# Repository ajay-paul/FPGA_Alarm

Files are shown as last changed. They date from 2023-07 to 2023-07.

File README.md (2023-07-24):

# FPGA_Alarm
 
Developed and implemented an alarm system using VHDL on a Nexys A7 FPGA board. Integrated a 4x4 Matrix keypad for user input. Employed Kicad to design a custom PCB for the project. The alarm system incorporated users to input a correct 4-digit password via the keypad, which was then displayed on a 7-segment display.
3D_View
Routing
FPGA_Correct
FPGA_False

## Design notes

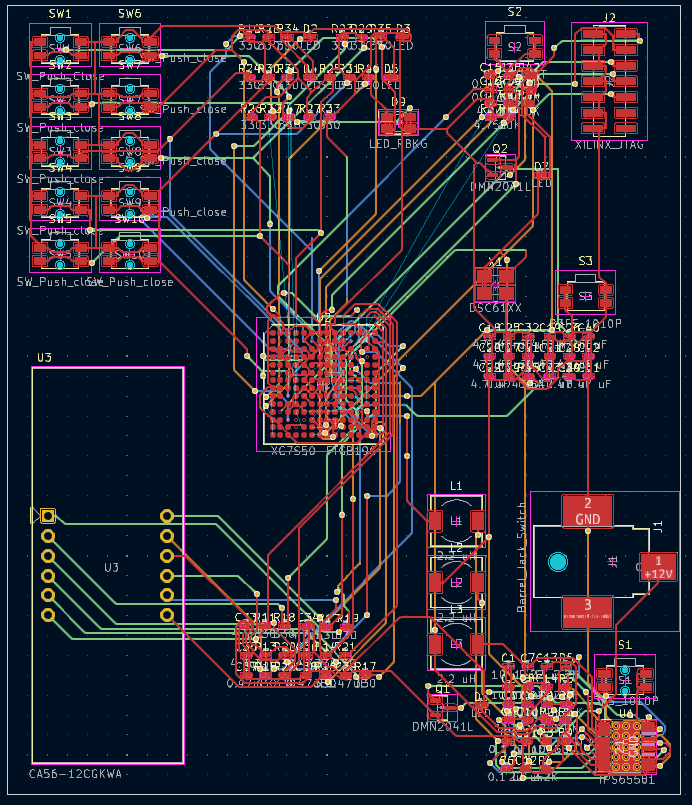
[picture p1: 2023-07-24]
PCB_Desgin/Routing.PNG

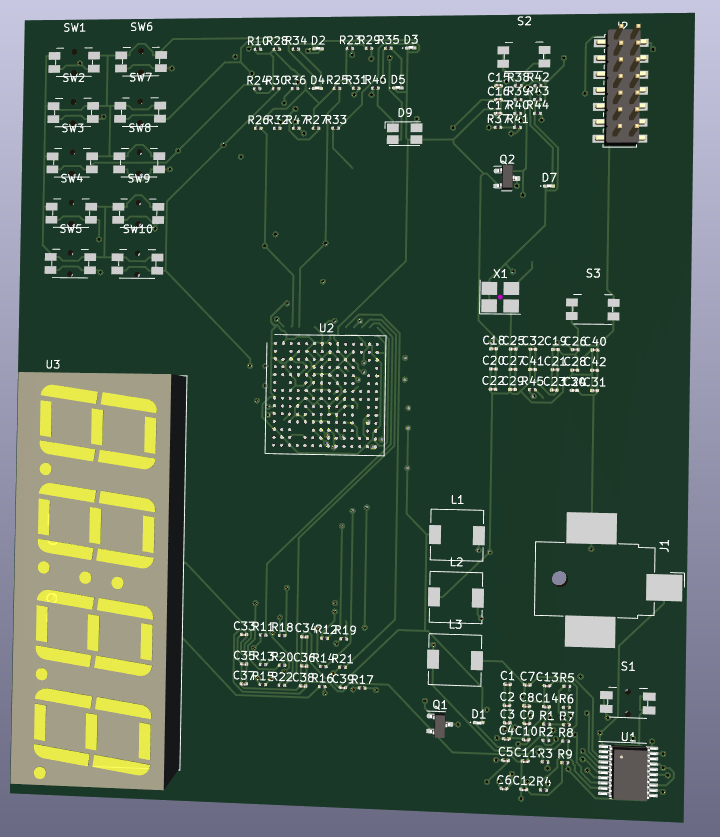
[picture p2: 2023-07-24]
PCB_Desgin/3D_View.PNG

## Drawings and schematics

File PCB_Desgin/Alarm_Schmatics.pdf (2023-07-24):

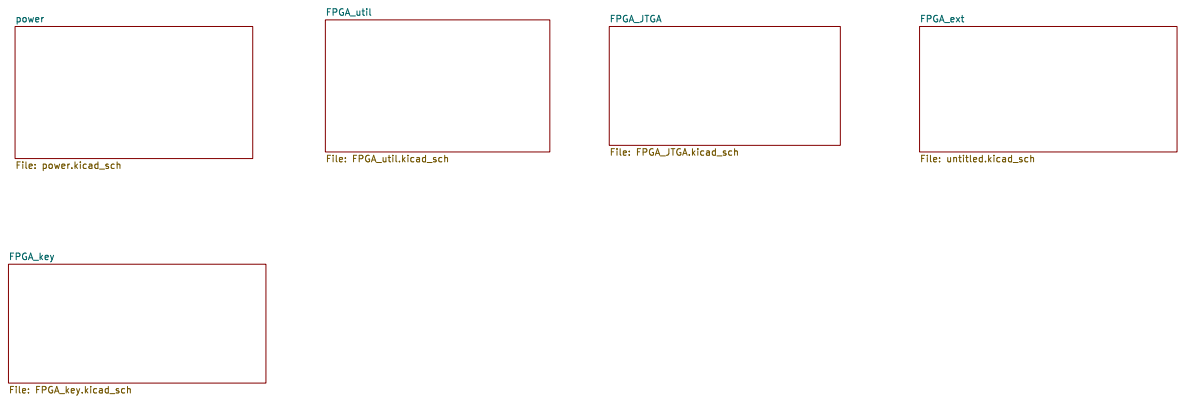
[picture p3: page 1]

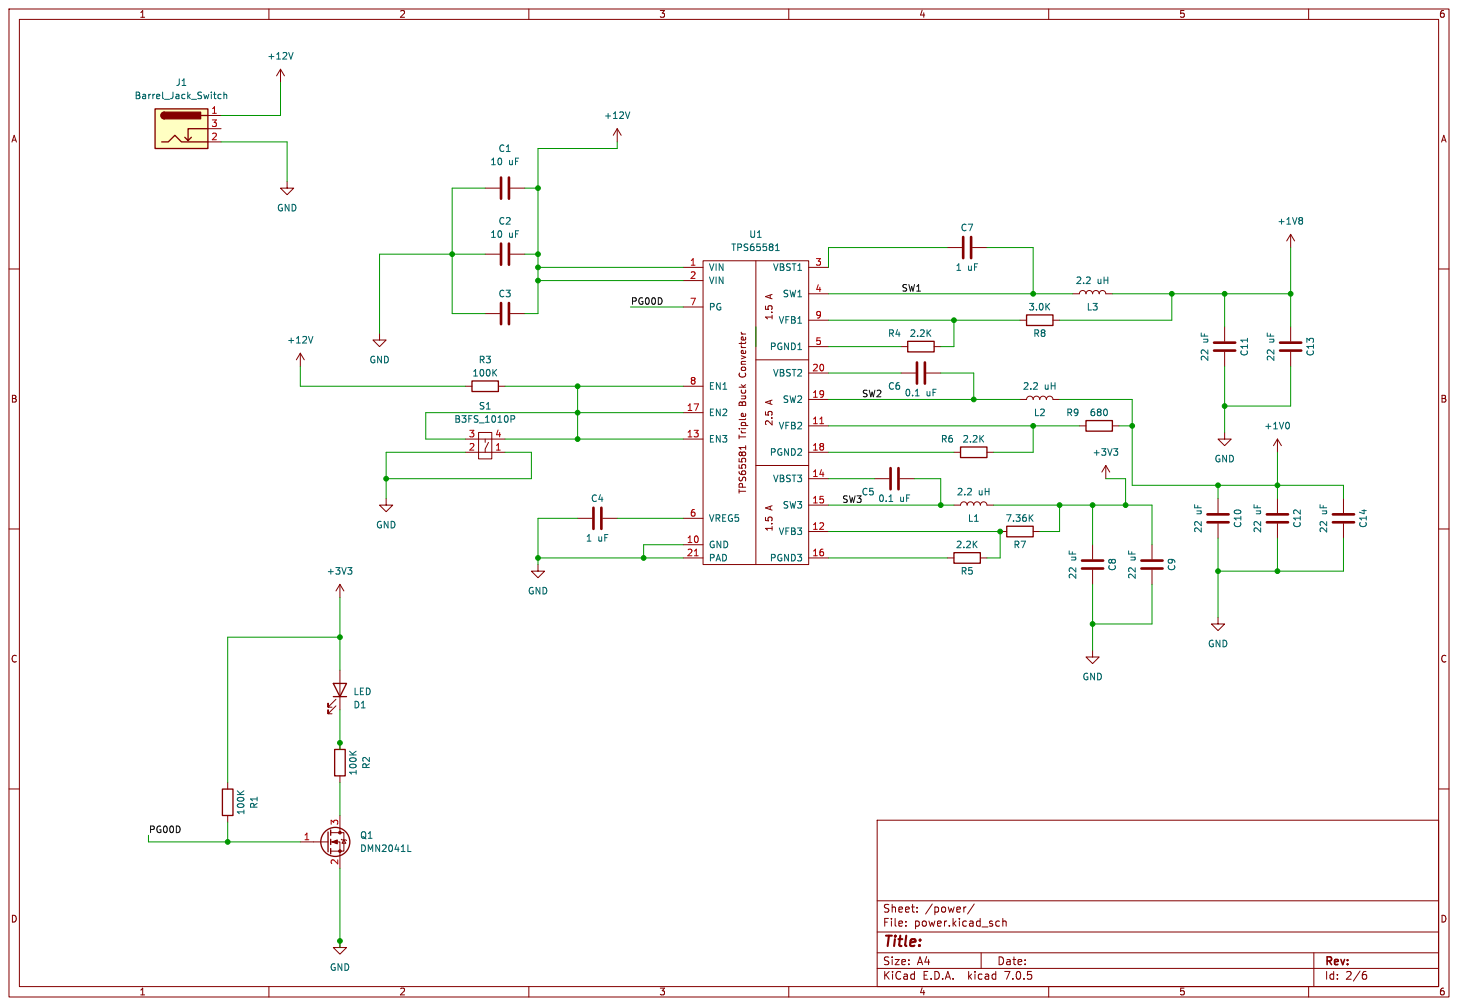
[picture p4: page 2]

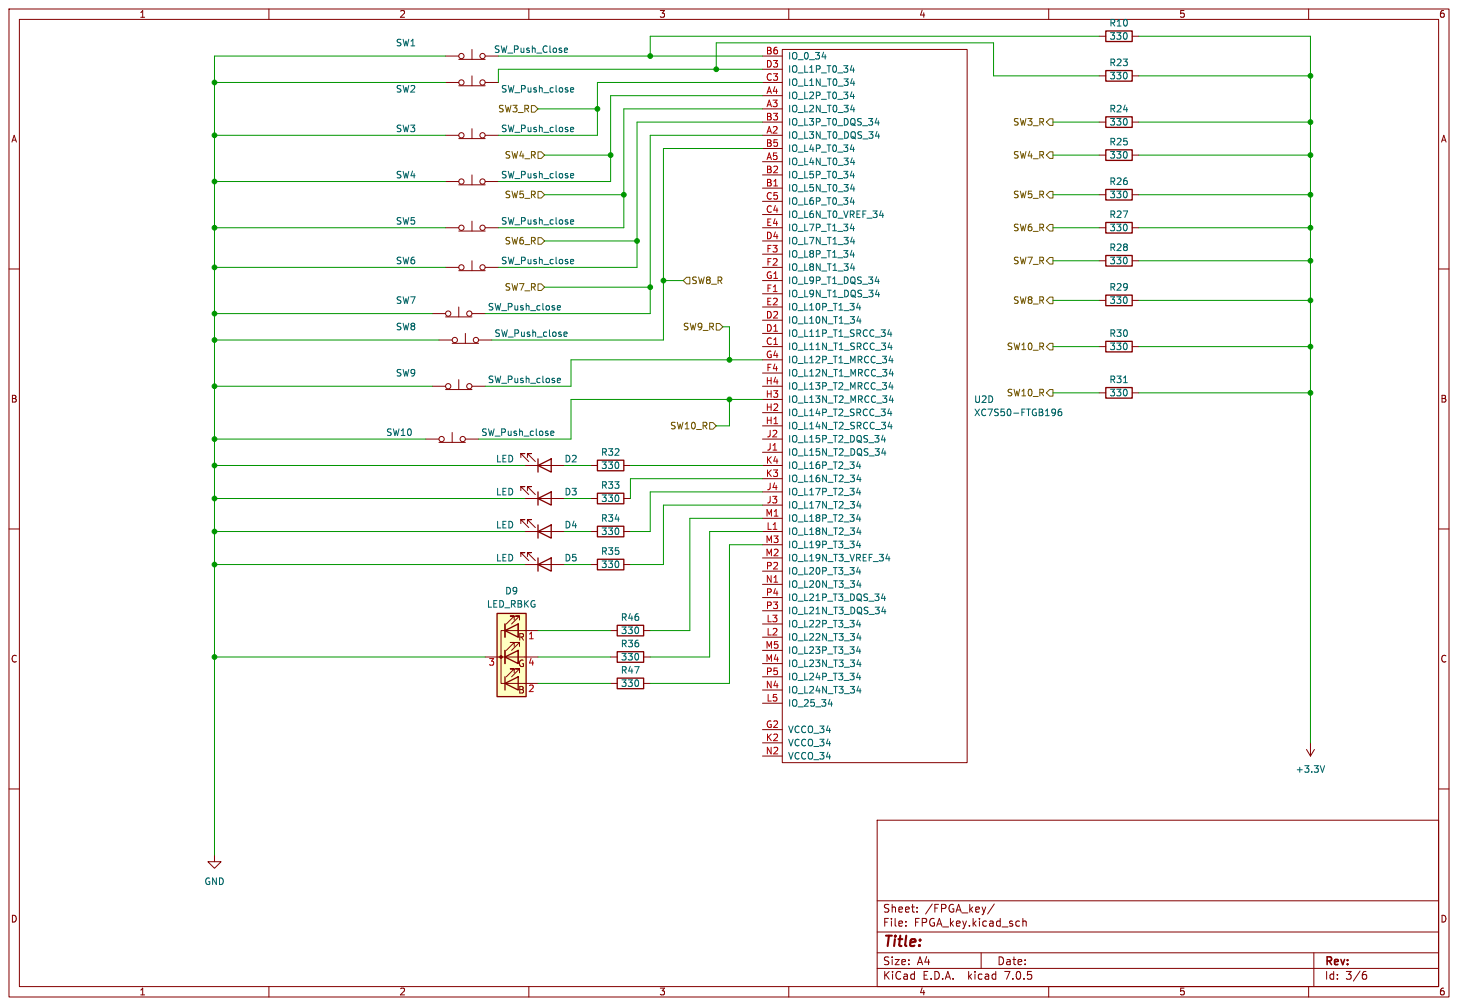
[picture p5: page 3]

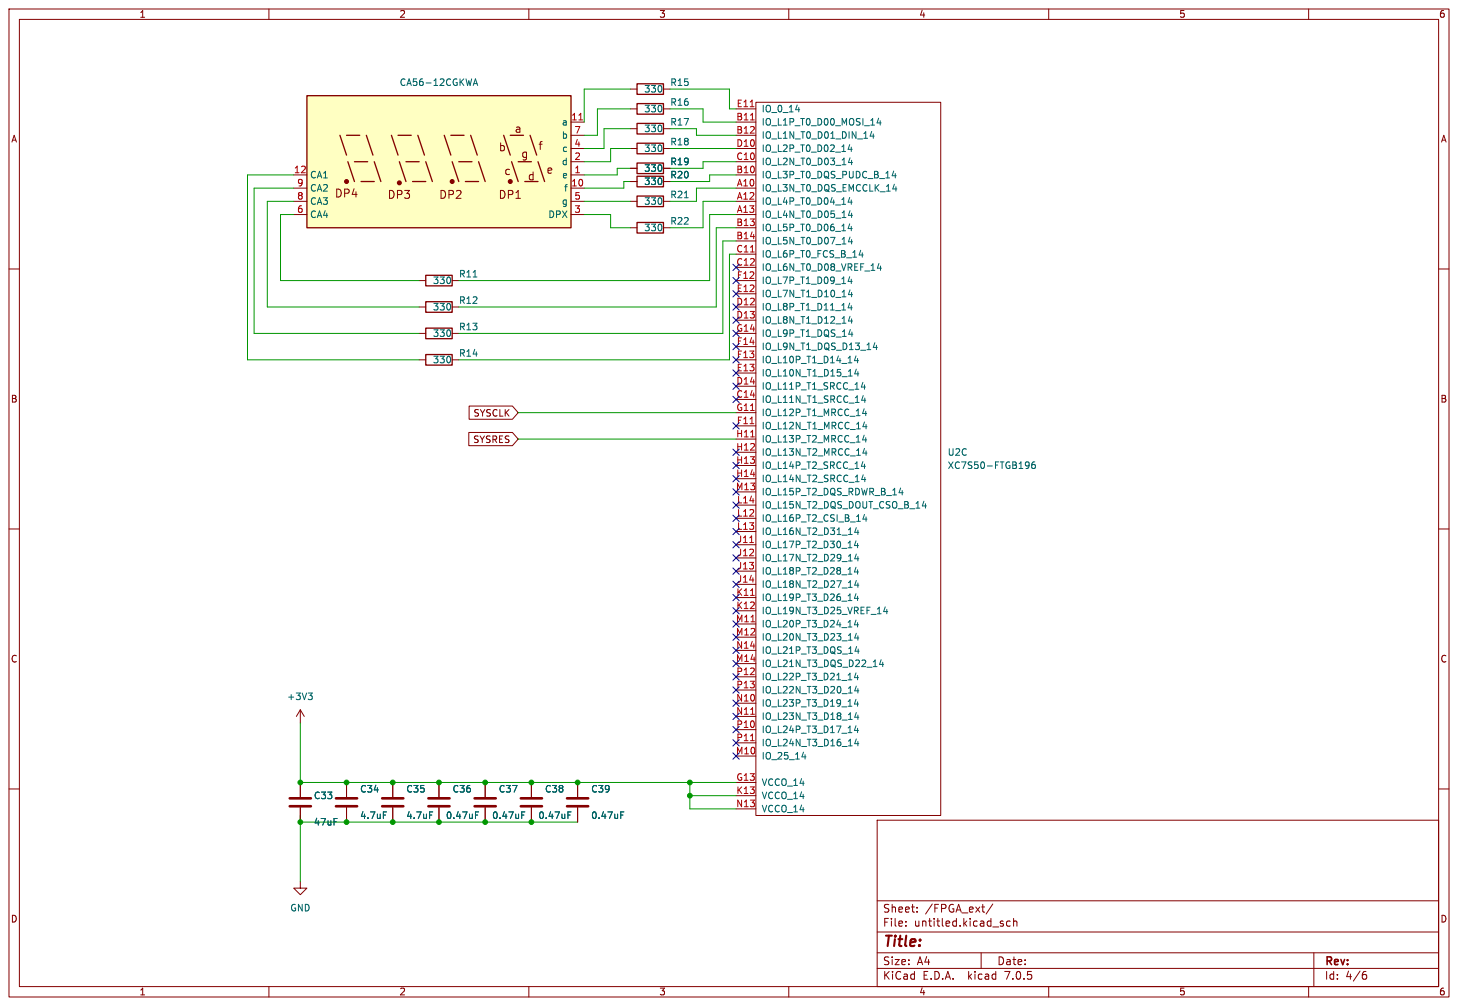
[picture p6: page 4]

Id: 4/6 Title: File: untitled.kicad_sch Sheet: /FPGA_ext/ C39

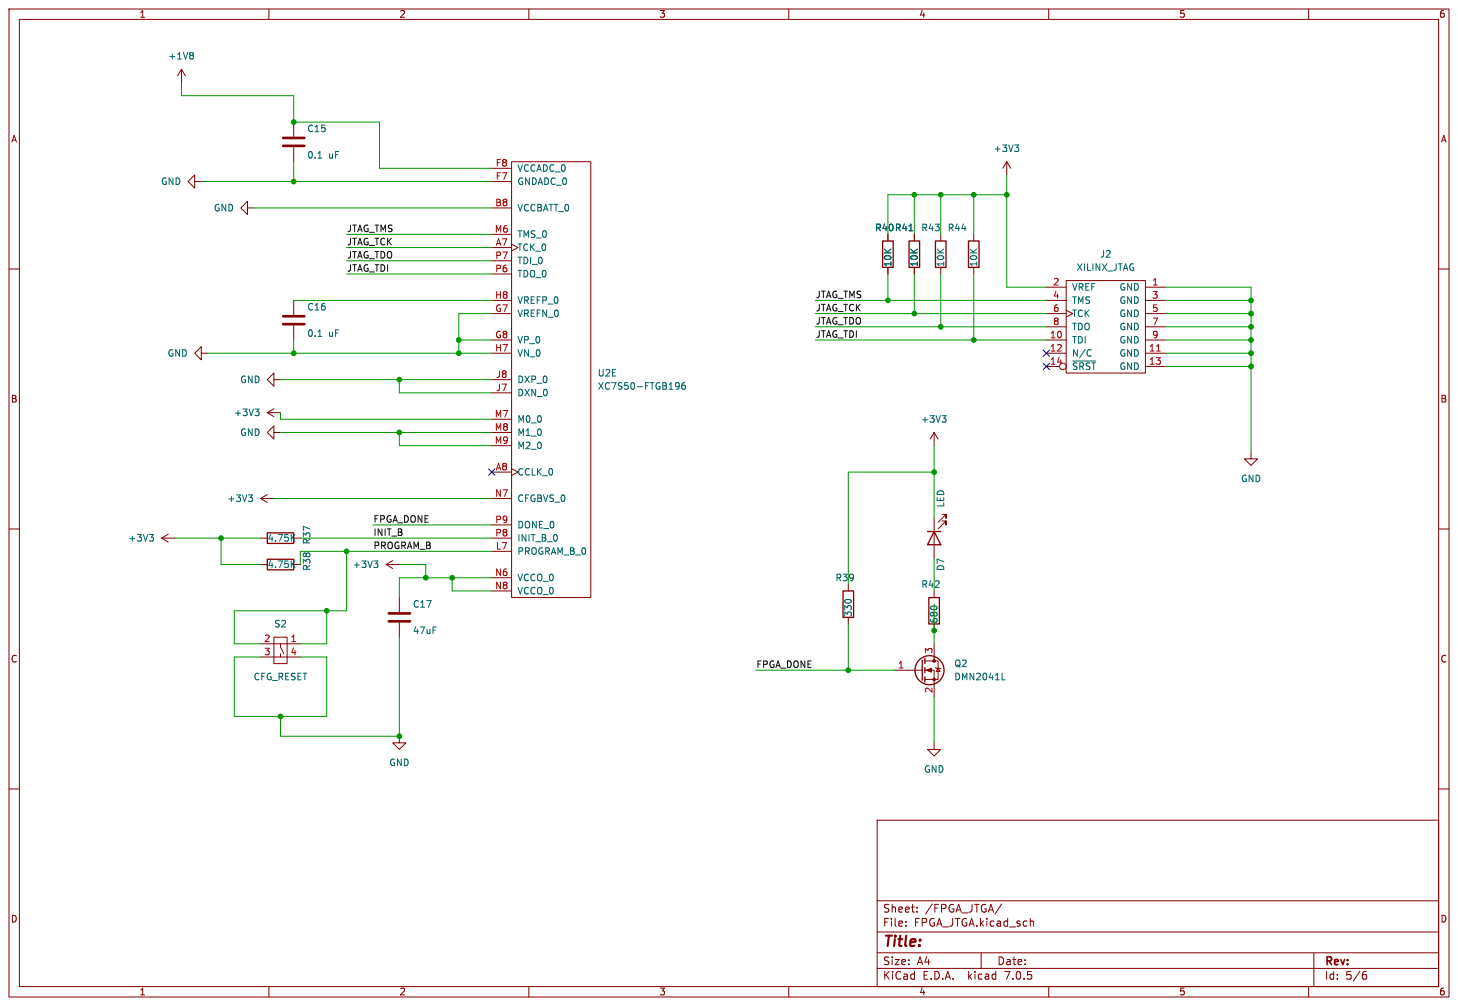
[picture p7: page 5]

Id: 5/6 Title: File: FPGA_JTGA.kicad_sch Sheet: /FPGA_JTGA/

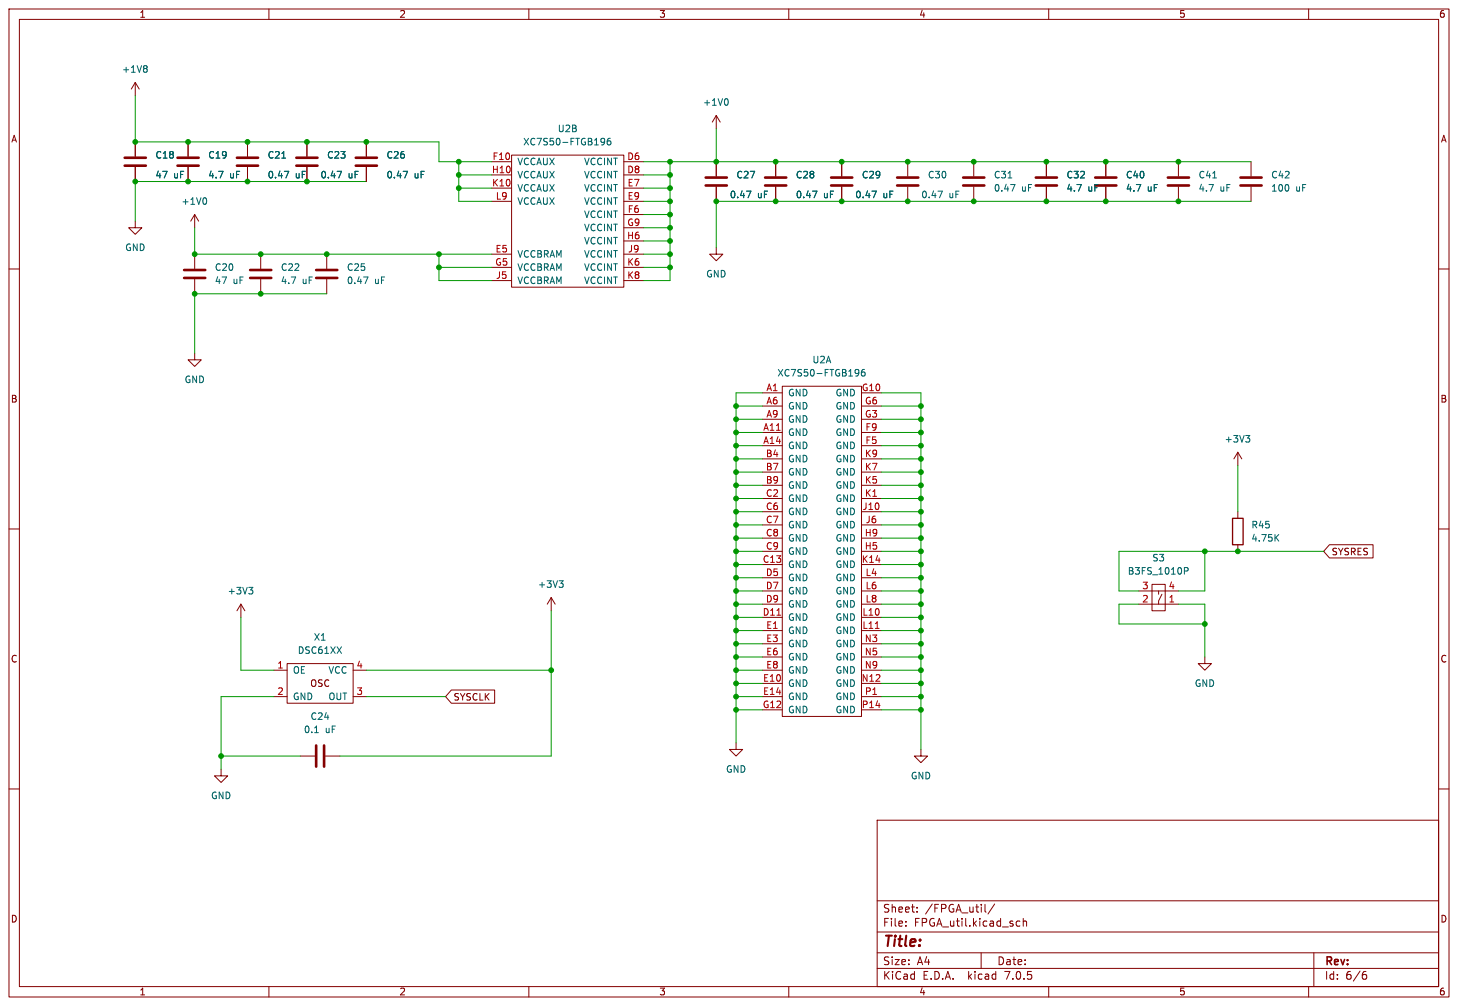
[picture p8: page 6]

Id: 6/6 Title: File: FPGA_util.kicad_sch Sheet: /FPGA_util/

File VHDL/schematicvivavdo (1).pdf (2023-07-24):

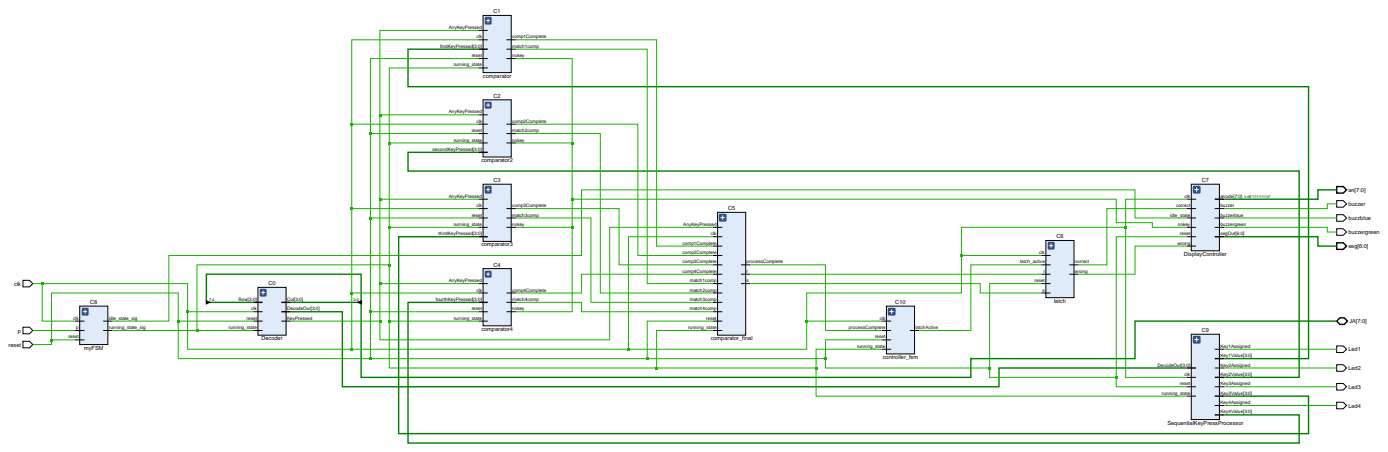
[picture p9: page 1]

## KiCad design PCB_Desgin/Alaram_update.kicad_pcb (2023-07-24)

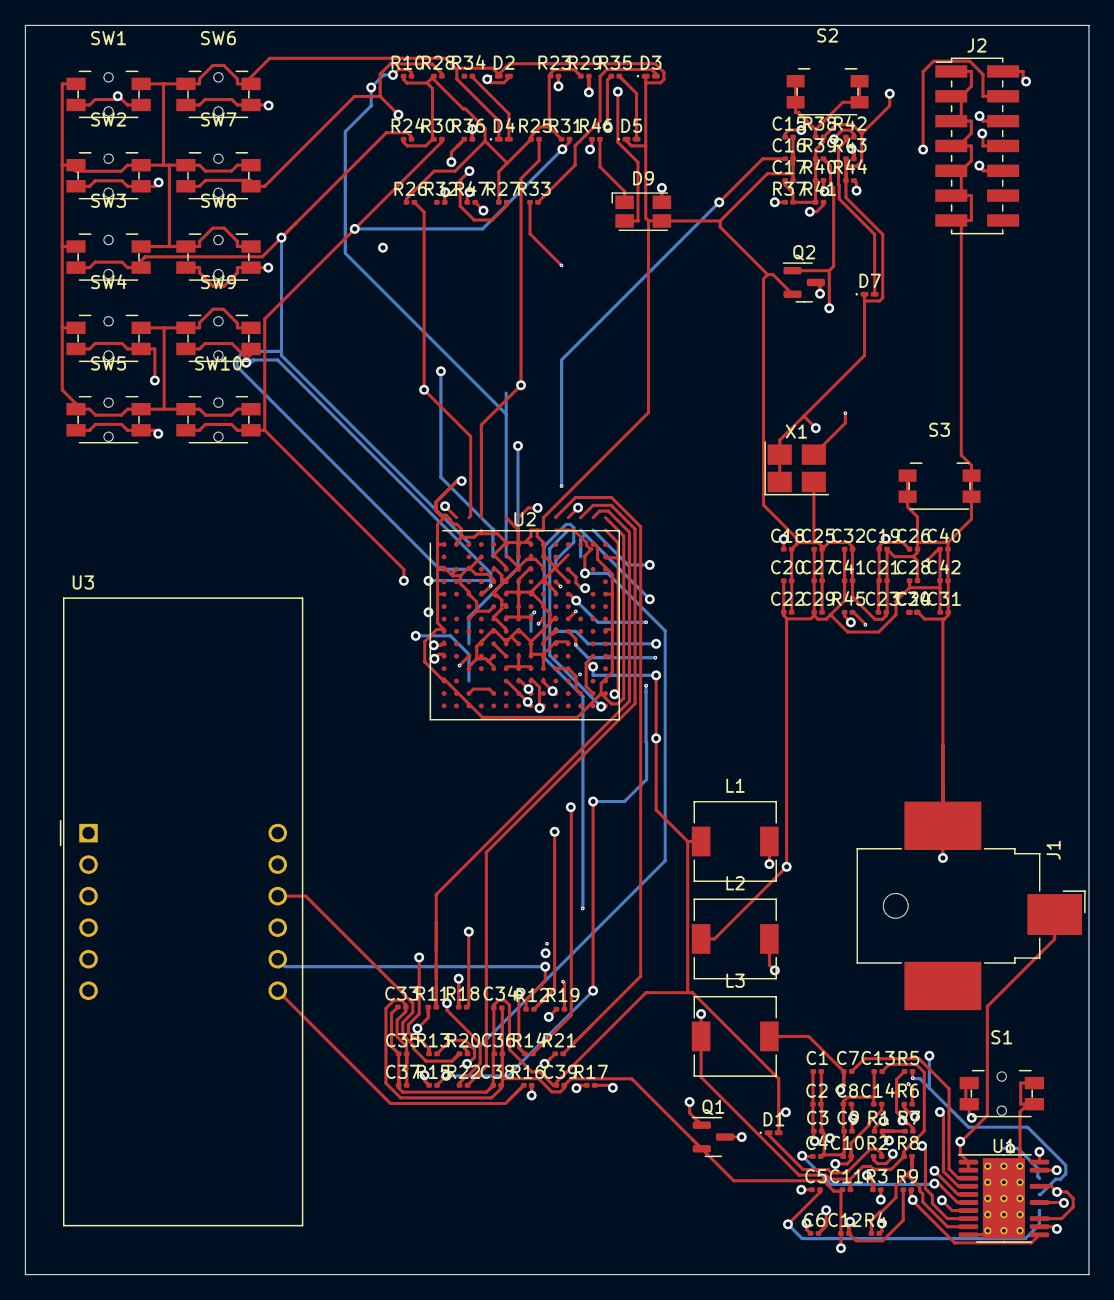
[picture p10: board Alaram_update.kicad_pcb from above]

Board: 4 copper layers, 85.7 x 100.6 mm, 120 parts (0 on the bottom side), 83 nets.

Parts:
C1, C2: 10 uF; C_0201_0603Metric
C3: C5; C_0201_0603Metric
C4, C7: 1 uF; C_0201_0603Metric
C5, C6, C15, C16, C24: 0.1 uF; C_0201_0603Metric
C8, C9, C10, C11, C12, C13, C14: 22 uF; C_0201_0603Metric
C17, C33: 47uF; C_0201_0603Metric
C18, C20: 47 uF; C_0201_0603Metric
C19, C22, C32, C40, C41: 4.7 uF; C_0201_0603Metric
C21, C23, C25, C26, C27, C28, C29, C30, C31: 0.47 uF; C_0201_0603Metric
C34, C35: 4.7uF; C_0201_0603Metric
C36, C37, C38, C39: 0.47uF; C_0201_0603Metric
C42: 100 uF; C_0201_0603Metric
D1, D2, D3, D4, D5, D7: LED; LED_0201_0603Metric_Pad0.64x0.40mm_HandSolder
D9: LED_RBKG; LED_Avago_PLCC4_3.2x2.8mm_CW
J1: Barrel_Jack_Switch; BarrelJack_CUI_PJ-036AH-SMT_Horizontal
J2: XILINX_JTAG; PinHeader_2x07_P2.00mm_Vertical_SMD
L1, L2, L3: 2.2 uH; L_6.3x6.3_H3
Q1, Q2: DMN2041L; SOT-23
R1, R2, R3: 100K; R_0201_0603Metric
R4, R5, R6: 2.2K; R_0201_0603Metric
R7: 7.36K; R_0201_0603Metric
R8: 3.0K; R_0201_0603Metric
R9, R42: 680; R_0201_0603Metric
R10, R11, R12, R13, R14, R15, R16, R17, R18, R19, R20, R21, R22, R23, R24, R25, R26, R27, R28, R29, R30, R31, R32, R33, R34, R35, R36, R39, R46, R47: 330; R_0201_0603Metric
R37, R38, R45: 4.75K; R_0201_0603Metric
R40, R41, R43, R44: 10K; R_0201_0603Metric
S1: B3FS_1010P; Panasonic_EVQPUL_EVQPUC
S2: CFG_RESET; Panasonic_EVQPUK_EVQPUB
S3: B3FS_1010P; Panasonic_EVQPUK_EVQPUB
SW1: SW_Push_Close; Panasonic_EVQPUL_EVQPUC
SW2, SW3, SW4, SW5, SW6, SW7, SW8, SW9, SW10: SW_Push_close; Panasonic_EVQPUL_EVQPUC
U1: TPS65581; HTSSOP-20-1EP_4.4x6.5mm_P0.65mm_EP3.4x6.5mm_Mask2.75x3.43mm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
U2: XC7S50-FTGB196; Xilinx_FTGB196
U3: CA56-12CGKWA
X1: DSC61XX; Oscillator_SMD_Abracon_ASE-4Pin_3.2x2.5mm_HandSoldering

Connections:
+1V0: C10.2, C12.2, C14.2, C20.1, C22.1, C25.1, C27.1, C28.1, C29.1, C30.1, C31.1, C32.1, C40.1, C41.1, C42.1, L2.1, R9.1, U2.D6 (VCCINT), U2.D8 (VCCINT), U2.E5 (VCCBRAM), U2.E7 (VCCINT), U2.E9 (VCCINT), U2.F6 (VCCINT), U2.G5 (VCCBRAM), U2.G9 (VCCINT), U2.H6 (VCCINT), U2.J5 (VCCBRAM), U2.J9 (VCCINT), U2.K6 (VCCINT), U2.K8 (VCCINT)
+1V8: C11.2, C13.2, C15.1, C18.1, C19.1, C21.1, C23.1, C26.1, L3.1, R8.1, U2.F8 (VCCADC_0), U2.F10 (VCCAUX), U2.H10 (VCCAUX), U2.K10 (VCCAUX), U2.L9 (VCCAUX)
+3.3V: R10.1, R23.1, R24.1, R25.1, R26.1, R27.1, R28.1, R29.1, R30.1, R31.1
+3V3: C8.2, C9.2, C17.1, C24.1, C33.1, C34.1, C35.1, C36.1, C37.1, C38.1, C39.1, D1.2 (A), D7.1 (K), J2.2 (VREF), L1.1, R1.2, R7.1, R37.2, R38.2, R39.1, R40.1, R41.1, R43.1, R44.1, R45.1, U2.G13 (VCCO_14), U2.K13 (VCCO_14), U2.M7 (M0_0), U2.N6 (VCCO_0), U2.N7 (CFGBVS_0), U2.N8 (VCCO_0), U2.N13 (VCCO_14), X1.1 (OE), X1.4 (VCC)
+12V: C1.1, C2.1, C3.1, J1.1, R3.2, U1.1 (VIN), U1.2 (VIN)
/FPGA_JTGA/FPGA_DONE: Q2.1 (G), R39.2, U2.P9 (DONE_0)
/FPGA_JTGA/INIT_B: R37.1, U2.P8 (INIT_B_0)
/FPGA_JTGA/JTAG_TCK: J2.6 (TCK), R41.2, U2.A7 (TCK_0)
/FPGA_JTGA/JTAG_TDI: J2.10 (TDI), R44.2, U2.P6 (TDO_0)
/FPGA_JTGA/JTAG_TDO: J2.8 (TDO), R43.2, U2.P7 (TDI_0)
/FPGA_JTGA/JTAG_TMS: J2.4 (TMS), R40.2, U2.M6 (TMS_0)
/FPGA_JTGA/PROGRAM_B: R38.1, S2.1, S2.2, U2.L7 (PROGRAM_B_0)
/FPGA_key/SW3_R: R24.2, SW3.2 (B), U2.C3 (IO_L1N_T0_34)
/FPGA_key/SW4_R: R25.2, SW4.2 (B), U2.A4 (IO_L2P_T0_34)
/FPGA_key/SW5_R: R26.2, SW5.2 (B), U2.A3 (IO_L2N_T0_34)
/FPGA_key/SW6_R: R27.2, SW6.2 (B), U2.B3 (IO_L3P_T0_DQS_34)
/FPGA_key/SW7_R: R28.2, SW7.2 (B), U2.A2 (IO_L3N_T0_DQS_34)
/FPGA_key/SW8_R: R29.2, SW8.2 (B), U2.B5 (IO_L4P_T0_34)
/FPGA_key/SW9_R: SW9.2 (B), U2.G4 (IO_L12P_T1_MRCC_34)
/FPGA_key/SW10_R: R30.2, R31.2, SW10.2 (B), U2.H3 (IO_L13N_T2_MRCC_34)
/power/PG00D: Q1.1 (G), R1.1, U1.7 (PG)
/power/SW1: C7.1, L3.2, U1.4 (SW1)
/power/SW2: C6.1, L2.2, U1.19 (SW2)
/power/SW3: C5.1, L1.2, U1.15 (SW3)
GND: C1.2, C2.2, C3.2, C4.2, C8.1, C9.1, C10.1, C11.1, C12.1, C13.1, C14.1, C15.2, C16.2, C17.2, C18.2, C19.2, C20.2, C21.2, C22.2, C23.2, C24.2, C25.2, C26.2, C27.2, C28.2, C29.2, C30.2, C31.2, C32.2, C33.2, C34.2, C35.2, C36.2, C37.2, C38.2, C39.2, C40.2, C41.2, C42.2, D2.1 (K), D3.1 (K), D4.1 (K), D5.1 (K), D9.3 (K), J1.2, J2.1 (GND), J2.3 (GND), J2.5 (GND), J2.7 (GND), J2.9 (GND), J2.11 (GND), J2.13 (GND), Q1.2 (S), Q2.2 (S), S1.1, S1.2, S3.1, S3.2, SW1.1 (A), SW2.1 (A), SW3.1 (A), SW4.1 (A), SW5.1 (A), SW6.1 (A), SW7.1 (A), SW8.1 (A), SW9.1 (A), SW10.1 (A), U1.10 (GND), U1.21 (PAD), U2.A1 (GND), U2.A6 (GND), U2.A9 (GND), U2.A11 (GND), U2.A14 (GND), U2.B4 (GND), U2.B7 (GND), U2.B8 (VCCBATT_0), U2.B9 (GND), U2.C2 (GND), U2.C6 (GND), U2.C7 (GND), U2.C8 (GND), U2.C9 (GND), U2.C13 (GND), U2.D5 (GND), U2.D7 (GND), U2.D9 (GND), U2.D11 (GND), U2.E1 (GND), U2.E3 (GND), U2.E6 (GND), U2.E8 (GND), U2.E10 (GND), U2.E14 (GND), U2.F5 (GND), U2.F7 (GNDADC_0), U2.F9 (GND), U2.G3 (GND), U2.G6 (GND), U2.G7 (VREFN_0), U2.G8 (VP_0), U2.G10 (GND), U2.G12 (GND), U2.H5 (GND), U2.H7 (VN_0), U2.H9 (GND), U2.J6 (GND), U2.J7 (DXN_0), U2.J8 (DXP_0), U2.J10 (GND), U2.K1 (GND), U2.K5 (GND), U2.K7 (GND), U2.K9 (GND), U2.K14 (GND), U2.L4 (GND), U2.L6 (GND), U2.L8 (GND), U2.L10 (GND), U2.L11 (GND), U2.M8 (M1_0), U2.M9 (M2_0), U2.N3 (GND), U2.N5 (GND), U2.N9 (GND), U2.N12 (GND), U2.P1 (GND), U2.P14 (GND), X1.2 (GND)
unnamed: D1.1 (K), R2.2
unnamed: D2.2 (A), R32.2
unnamed: D3.2 (A), R33.2
unnamed: D4.2 (A), R34.2
unnamed: D5.2 (A), R35.2
unnamed: D7.2 (A), R42.1
unnamed: D9.2 (BA), R47.2
unnamed: D9.4 (GA), R36.2
unnamed: D9.1 (RA), R46.2
unnamed: Q1.3 (D), R2.1
unnamed: Q2.3 (D), R42.2
unnamed: R10.2, SW1.2 (B), U2.B6 (IO_0_34)
unnamed: R23.2, SW2.2 (B), U2.D3 (IO_L1P_T0_34)
unnamed: R3.1, U1.8 (EN1), U1.13 (EN3), U1.17 (EN2)
unnamed: R4.2, U1.5 (PGND1)
unnamed: R6.2, U1.18 (PGND2)
unnamed: R5.2, U1.16 (PGND3)
unnamed: C7.2, U1.3 (VBST1)
unnamed: C6.2, U1.20 (VBST2)
unnamed: C5.2, U1.14 (VBST3)
unnamed: R4.1, R8.2, U1.9 (VFB1)
unnamed: R6.1, R9.2, U1.11 (VFB2)
unnamed: R5.1, R7.2, U1.12 (VFB3)
unnamed: C4.1, U1.6 (VREG5)
unnamed: R15.2, U2.E11 (IO_0_14)
unnamed: R17.2, U2.B12 (IO_L1N_T0_D01_DIN_14)
unnamed: R16.2, U2.B11 (IO_L1P_T0_D00_MOSI_14)
unnamed: R19.2, U2.C10 (IO_L2N_T0_D03_14)
unnamed: R18.2, U2.D10 (IO_L2P_T0_D02_14)
unnamed: R21.2, U2.A10 (IO_L3N_T0_DQS_EMCCLK_14)
unnamed: R20.2, U2.B10 (IO_L3P_T0_DQS_PUDC_B_14)
unnamed: R11.2, U2.A13 (IO_L4N_T0_D05_14)
unnamed: R22.2, U2.A12 (IO_L4P_T0_D04_14)
unnamed: R13.2, U2.B14 (IO_L5N_T0_D07_14)
unnamed: R12.2, U2.B13 (IO_L5P_T0_D06_14)
unnamed: R14.2, U2.C11 (IO_L6P_T0_FCS_B_14)
unnamed: R33.1, U2.K3 (IO_L16N_T2_34)
unnamed: R32.1, U2.K4 (IO_L16P_T2_34)
unnamed: R35.1, U2.J3 (IO_L17N_T2_34)
unnamed: R34.1, U2.J4 (IO_L17P_T2_34)
unnamed: R36.1, U2.L1 (IO_L18N_T2_34)
unnamed: R46.1, U2.M1 (IO_L18P_T2_34)
unnamed: R47.1, U2.M3 (IO_L19P_T3_34)
unnamed: C16.1, U2.H8 (VREFP_0)
unnamed: R14.1, U3.12 (CA1)
unnamed: R13.1, U3.9 (CA2)
unnamed: R12.1, U3.8 (CA3)
unnamed: R11.1, U3.6 (CA4)
unnamed: R22.1, U3.3 (DPX)
unnamed: R15.1, U3.11 (a)
unnamed: R16.1, U3.7 (b)
unnamed: R17.1, U3.4 (c)
unnamed: R18.1, U3.2 (d)
unnamed: R19.1, U3.1 (e)
unnamed: R20.1, U3.10 (f)
unnamed: R21.1, U3.5 (g)
SYSCLK: U2.G11 (IO_L12P_T1_MRCC_14), X1.3 (OUT)
SYSRES: R45.2, U2.H11 (IO_L13P_T2_MRCC_14)

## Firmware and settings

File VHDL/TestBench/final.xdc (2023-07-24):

## This file is a general .xdc for the Nexys A7-100T
## To use it in a project:
## - uncomment the lines corresponding to used pins
## - rename the used ports (in each line, after get_ports) according to the top level signal names in the project

## Clock signal
set_property -dict { PACKAGE_PIN E3    IOSTANDARD LVCMOS33 } [get_ports { clk }]; #IO_L12P_T1_MRCC_35 Sch=clk100mhz
#create_clock -add -name sys_clk_pin -period 10.00 -waveform {0 5} [get_ports {CLK100MHZ}];


##Switches
set_property -dict { PACKAGE_PIN J15   IOSTANDARD LVCMOS33 } [get_ports { reset }]; #IO_L24N_T3_RS0_15 Sch=sw[0]
set_property -dict { PACKAGE_PIN L16   IOSTANDARD LVCMOS33 } [get_ports { p }]; #IO_L3N_T0_DQS_EMCCLK_14 Sch=sw[1]
#set_property -dict { PACKAGE_PIN M13   IOSTANDARD LVCMOS33 } [get_ports { SW[2] }]; #IO_L6N_T0_D08_VREF_14 Sch=sw[2]
#set_property -dict { PACKAGE_PIN R15   IOSTANDARD LVCMOS33 } [get_ports { SW[3] }]; #IO_L13N_T2_MRCC_14 Sch=sw[3]
#set_property -dict { PACKAGE_PIN R17   IOSTANDARD LVCMOS33 } [get_ports { SW[4] }]; #IO_L12N_T1_MRCC_14 Sch=sw[4]
#set_property -dict { PACKAGE_PIN T18   IOSTANDARD LVCMOS33 } [get_ports { SW[5] }]; #IO_L7N_T1_D10_14 Sch=sw[5]
#set_property -dict { PACKAGE_PIN U18   IOSTANDARD LVCMOS33 } [get_ports { SW[6] }]; #IO_L17N_T2_A13_D29_14 Sch=sw[6]
#set_property -dict { PACKAGE_PIN R13   IOSTANDARD LVCMOS33 } [get_ports { SW[7] }]; #IO_L5N_T0_D07_14 Sch=sw[7]
#set_property -dict { PACKAGE_PIN T8    IOSTANDARD LVCMOS18 } [get_ports { SW[8] }]; #IO_L24N_T3_34 Sch=sw[8]
#set_property -dict { PACKAGE_PIN U8    IOSTANDARD LVCMOS18 } [get_ports { SW[9] }]; #IO_25_34 Sch=sw[9]
#set_property -dict { PACKAGE_PIN R16   IOSTANDARD LVCMOS33 } [get_ports { SW[10] }]; #IO_L15P_T2_DQS_RDWR_B_14 Sch=sw[10]
#set_property -dict { PACKAGE_PIN T13   IOSTANDARD LVCMOS33 } [get_ports { SW[11] }]; #IO_L23P_T3_A03_D19_14 Sch=sw[11]
#set_property -dict { PACKAGE_PIN H6    IOSTANDARD LVCMOS33 } [get_ports { SW[12] }]; #IO_L24P_T3_35 Sch=sw[12]
#set_property -dict { PACKAGE_PIN U12   IOSTANDARD LVCMOS33 } [get_ports { SW[13] }]; #IO_L20P_T3_A08_D24_14 Sch=sw[13]
#set_property -dict { PACKAGE_PIN U11   IOSTANDARD LVCMOS33 } [get_ports { SW[14] }]; #IO_L19N_T3_A09_D25_VREF_14 Sch=sw[14]
#set_property -dict { PACKAGE_PIN V10   IOSTANDARD LVCMOS33 } [get_ports { SW[15] }]; #IO_L21P_T3_DQS_14 Sch=sw[15]

### LEDs
set_property -dict { PACKAGE_PIN H17   IOSTANDARD LVCMOS33 } [get_ports { Led1 }]; #IO_L18P_T2_A24_15 Sch=led[0]
set_property -dict { PACKAGE_PIN K15   IOSTANDARD LVCMOS33 } [get_ports { Led2 }]; #IO_L24P_T3_RS1_15 Sch=led[1]
set_property -dict { PACKAGE_PIN J13   IOSTANDARD LVCMOS33 } [get_ports { Led3 }]; #IO_L17N_T2_A25_15 Sch=led[2]
set_property -dict { PACKAGE_PIN N14   IOSTANDARD LVCMOS33 } [get_ports { Led4 }]; #IO_L8P_T1_D11_14 Sch=led[3]
#set_property -dict { PACKAGE_PIN R18   IOSTANDARD LVCMOS33 } [get_ports { LED[4] }]; #IO_L7P_T1_D09_14 Sch=led[4]
#set_property -dict { PACKAGE_PIN V17   IOSTANDARD LVCMOS33 } [get_ports { LED[5] }]; #IO_L18N_T2_A11_D27_14 Sch=led[5]
#set_property -dict { PACKAGE_PIN U17   IOSTANDARD LVCMOS33 } [get_ports { LED[6] }]; #IO_L17P_T2_A14_D30_14 Sch=led[6]
#set_property -dict { PACKAGE_PIN U16   IOSTANDARD LVCMOS33 } [get_ports { LED[7] }]; #IO_L18P_T2_A12_D28_14 Sch=led[7]
#set_property -dict { PACKAGE_PIN V16   IOSTANDARD LVCMOS33 } [get_ports { LED[8] }]; #IO_L16N_T2_A15_D31_14 Sch=led[8]
#set_property -dict { PACKAGE_PIN T15   IOSTANDARD LVCMOS33 } [get_ports { LED[9] }]; #IO_L14N_T2_SRCC_14 Sch=led[9]
#set_property -dict { PACKAGE_PIN U14   IOSTANDARD LVCMOS33 } [get_ports { LED[10] }]; #IO_L22P_T3_A05_D21_14 Sch=led[10]
#set_property -dict { PACKAGE_PIN T16   IOSTANDARD LVCMOS33 } [get_ports { LED[11] }]; #IO_L15N_T2_DQS_DOUT_CSO_B_14 Sch=led[11]
#set_property -dict { PACKAGE_PIN V15   IOSTANDARD LVCMOS33 } [get_ports { LED[12] }]; #IO_L16P_T2_CSI_B_14 Sch=led[12]
#set_property -dict { PACKAGE_PIN V14   IOSTANDARD LVCMOS33 } [get_ports { LED[13] }]; #IO_L22N_T3_A04_D20_14 Sch=led[13]
#set_property -dict { PACKAGE_PIN V12   IOSTANDARD LVCMOS33 } [get_ports { LED[14] }]; #IO_L20N_T3_A07_D23_14 Sch=led[14]
#set_property -dict { PACKAGE_PIN V11   IOSTANDARD LVCMOS33 } [get_ports { LED[15] }]; #IO_L21N_T3_DQS_A06_D22_14 Sch=led[15]

## RGB LEDs
set_property -dict { PACKAGE_PIN R12   IOSTANDARD LVCMOS33 } [get_ports { buzzblue }]; #IO_L5P_T0_D06_14 Sch=led16_b
set_property -dict { PACKAGE_PIN M16   IOSTANDARD LVCMOS33 } [get_ports { buzzergreen }]; #IO_L10P_T1_D14_14 Sch=led16_g
set_property -dict { PACKAGE_PIN N15   IOSTANDARD LVCMOS33 } [get_ports { buzzer }]; #IO_L11P_T1_SRCC_14 Sch=led16_r
#set_property -dict { PACKAGE_PIN G14   IOSTANDARD LVCMOS33 } [get_ports { Led1 }]; #IO_L15N_T2_DQS_ADV_B_15 Sch=led17_b
#set_property -dict { PACKAGE_PIN R11   IOSTANDARD LVCMOS33 } [get_ports { Led2 }]; #IO_0_14 Sch=led17_g
#set_property -dict { PACKAGE_PIN N16   IOSTANDARD LVCMOS33 } [get_ports { Led6 }]; #IO_L11N_T1_SRCC_14 Sch=led17_r
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
